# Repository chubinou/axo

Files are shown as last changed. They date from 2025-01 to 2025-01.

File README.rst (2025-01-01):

AXO
###

A simple eurorack logic module

* `axo` full schematics
* `axo_back` main board
* `axo_middle` connector board
* `axo_front` face plate

LICENSE
#######

This work by Pierre Lamot is licensed under CC BY-NC 4.0. To view a copy of this license, visit https://creativecommons.org/licenses/by-nc/4.0/

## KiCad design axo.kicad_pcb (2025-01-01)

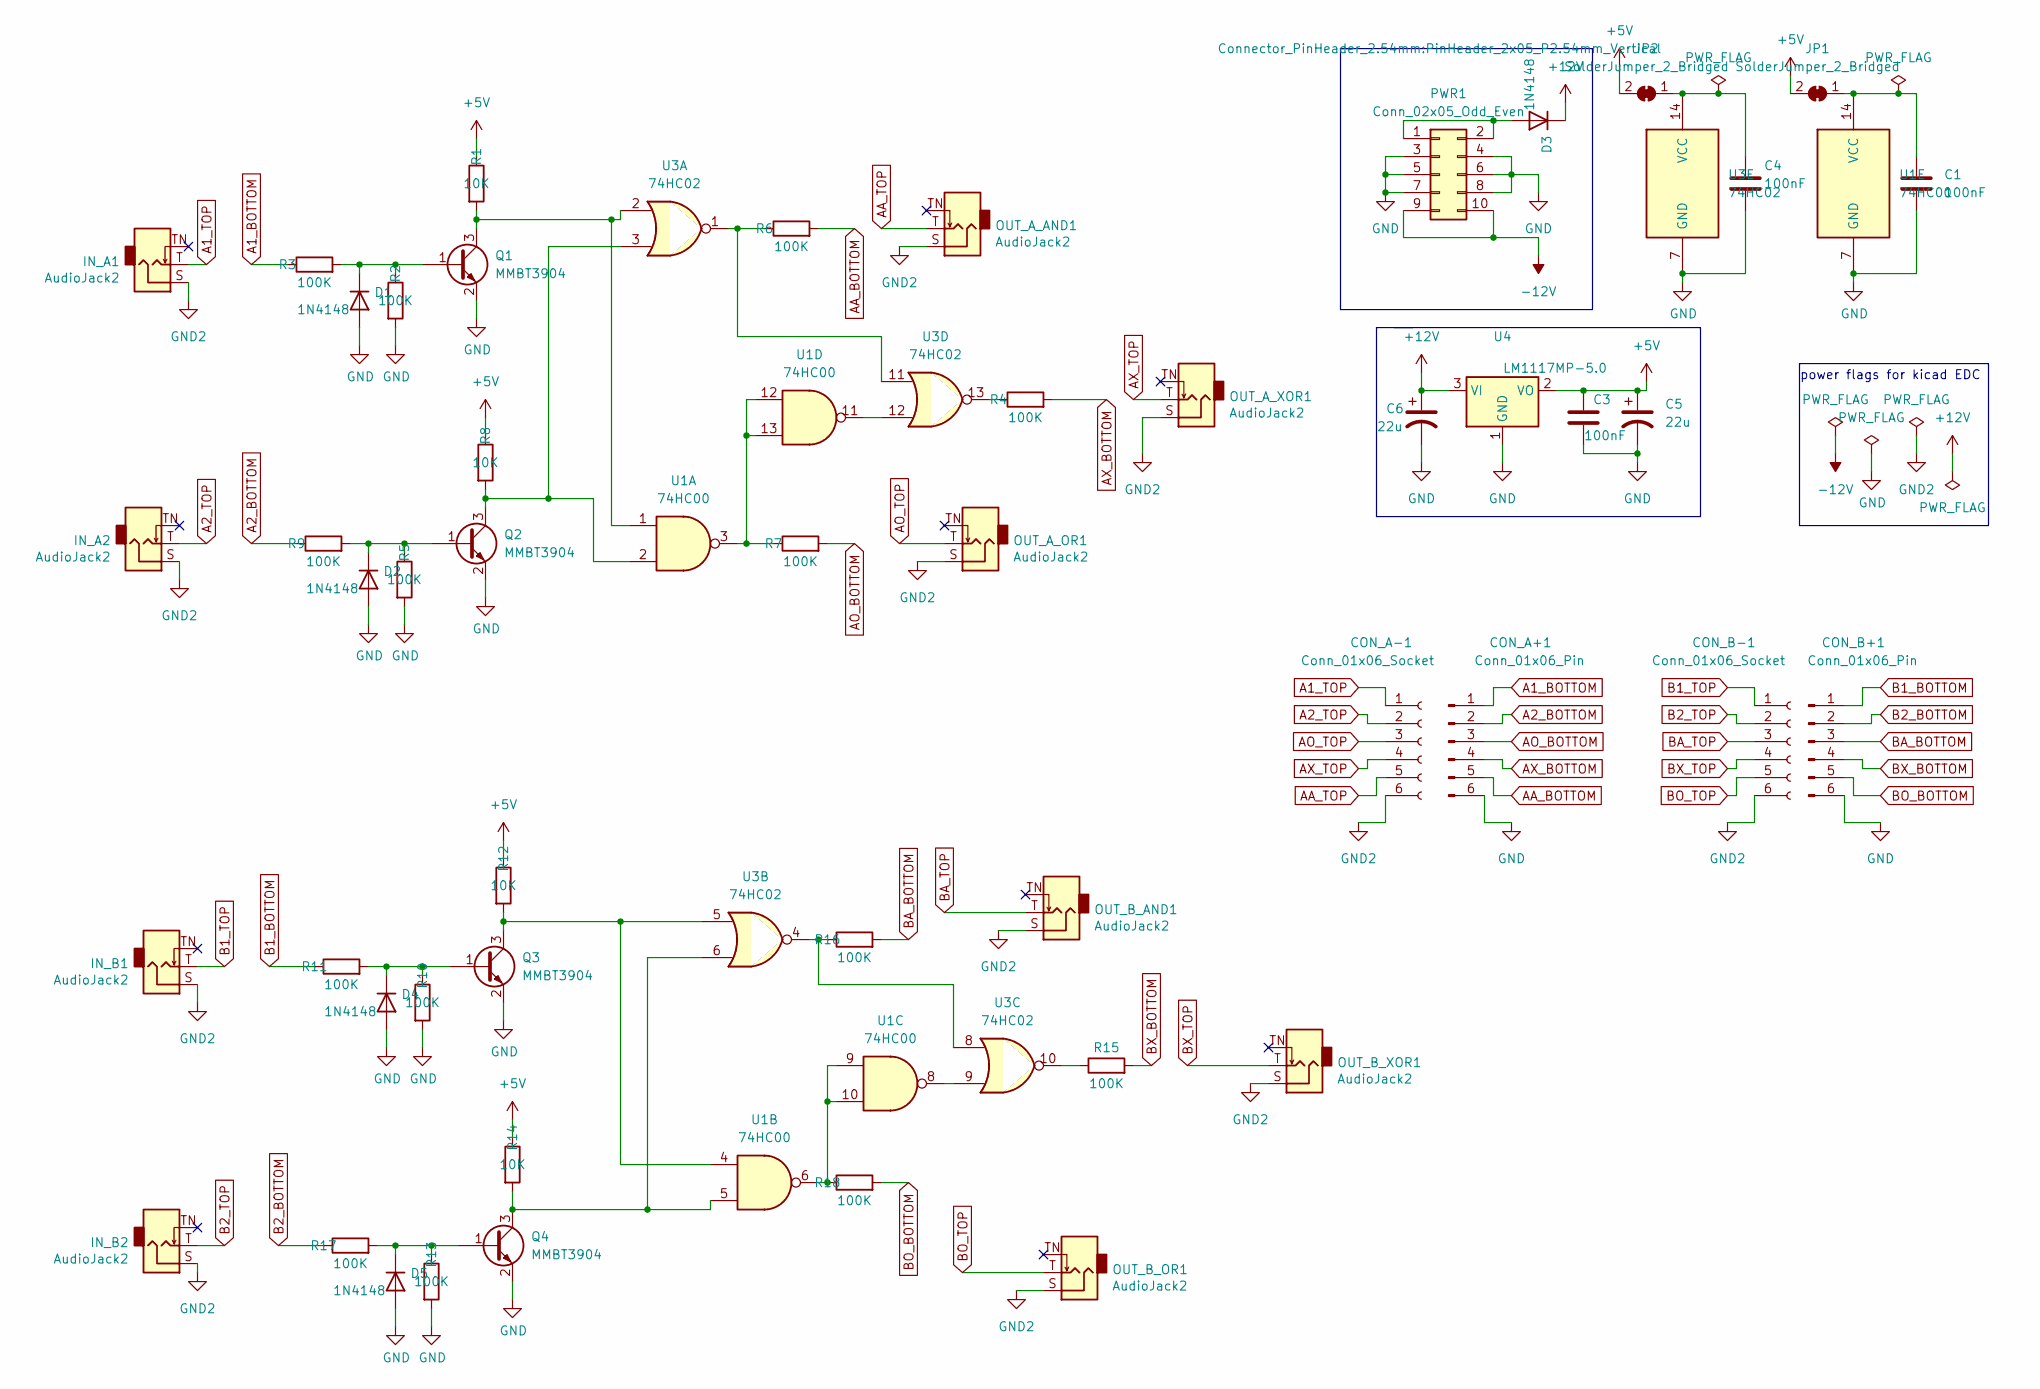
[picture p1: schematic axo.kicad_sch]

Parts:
C1, C3, C4: 100nF; C_0805_2012Metric; LCSC C49678
C5, C6: 22u; CP_Elec_6.3x5.4; LCSC C3001215
CON_A+1: Conn_01x06_Pin; PinHeader_1x06_P2.54mm_Vertical
CON_A-1: Conn_01x06_Socket; PinSocket_1x06_P2.54mm_Vertical
CON_B+1: Conn_01x06_Pin; PinHeader_1x06_P2.54mm_Vertical
CON_B-1: Conn_01x06_Socket; PinSocket_1x06_P2.54mm_Vertical
D1, D2, D3, D4, D5: 1N4148; D_SOD-323; LCSC C2128
IN_A1, IN_A2: AudioJack2; Jack_3.5mm_QingPu_WQP-PJ398SM_Vertical
IN_B1, IN_B2: AudioJack2; Jack_3.5mm_QingPu_WQP-PJ398SM_Vertical
JP1, JP2: SolderJumper_2_Bridged; SolderJumper-2_P1.3mm_Bridged_Pad1.0x1.5mm
OUT_A_AND1: AudioJack2; Jack_3.5mm_QingPu_WQP-PJ398SM_Vertical
OUT_A_OR1: AudioJack2; Jack_3.5mm_QingPu_WQP-PJ398SM_Vertical
OUT_A_XOR1: AudioJack2; Jack_3.5mm_QingPu_WQP-PJ398SM_Vertical
OUT_B_AND1: AudioJack2; Jack_3.5mm_QingPu_WQP-PJ398SM_Vertical
OUT_B_OR1: AudioJack2; Jack_3.5mm_QingPu_WQP-PJ398SM_Vertical
OUT_B_XOR1: AudioJack2; Jack_3.5mm_QingPu_WQP-PJ398SM_Vertical
PWR1: Conn_02x05_Odd_Even; PinHeader_2x05_P2.54mm_Vertical
Q1, Q2, Q3, Q4: MMBT3904; SOT-23; LCSC C20526
R1, R8, R12, R14: 10K; R_0603_1608Metric; LCSC C25804
R2, R3, R4, R5, R6, R7, R9, R10, R11, R13, R15, R16, R17, R18: 100K; R_0603_1608Metric; LCSC C25803
U1: 74HC00; SOIC-14_3.9x8.7mm_P1.27mm; LCSC C155451
U3: 74HC02; SOIC-14_3.9x8.7mm_P1.27mm; LCSC C5588
U4: LM1117MP-5.0; SOT-223; LCSC C6187

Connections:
+5V: C3.1, C5.1, JP1.2 (B), JP2.2 (B), R1.1, R8.1, R12.1, R14.1, U4.2 (VO)
+12V: C6.1, D3.1 (K), U4.3 (VI)
-12V: PWR1.9, PWR1.10
A1_BOTTOM: CON_A+1.1, R3.1
A1_TOP: CON_A-1.1, IN_A1.T
A2_BOTTOM: CON_A+1.2, R9.1
A2_TOP: CON_A-1.2, IN_A2.T
AA_BOTTOM: CON_A+1.5, R6.2
AA_TOP: CON_A-1.5, OUT_A_AND1.T
AO_BOTTOM: CON_A+1.3, R7.2
AO_TOP: CON_A-1.3, OUT_A_OR1.T
AX_BOTTOM: CON_A+1.4, R4.2
AX_TOP: CON_A-1.4, OUT_A_XOR1.T
B1_BOTTOM: CON_B+1.1, R11.1
B1_TOP: CON_B-1.1, IN_B1.T
B2_BOTTOM: CON_B+1.2, R17.1
B2_TOP: CON_B-1.2, IN_B2.T
BA_BOTTOM: CON_B+1.3, R16.2
BA_TOP: CON_B-1.3, OUT_B_AND1.T
BO_BOTTOM: CON_B+1.5, R18.2
BO_TOP: CON_B-1.5, OUT_B_OR1.T
BX_BOTTOM: CON_B+1.4, R15.2
BX_TOP: CON_B-1.4, OUT_B_XOR1.T
GND: C1.2, C3.2, C4.2, C5.2, C6.2, CON_A+1.6, CON_B+1.6, D1.2 (A), D2.2 (A), D4.2 (A), D5.2 (A), PWR1.3, PWR1.4, PWR1.5, PWR1.6, PWR1.7, PWR1.8, Q1.2 (E), Q2.2 (E), Q3.2 (E), Q4.2 (E), R2.2, R5.2, R10.2, R13.2, U1.7 (GND), U3.7 (GND), U4.1 (GND)
GND2: CON_A-1.6, CON_B-1.6, IN_A1.S, IN_A2.S, IN_B1.S, IN_B2.S, OUT_A_AND1.S, OUT_A_OR1.S, OUT_A_XOR1.S, OUT_B_AND1.S, OUT_B_OR1.S, OUT_B_XOR1.S
unnamed: D1.1 (K), Q1.1 (B), R2.1, R3.2
unnamed: D2.1 (K), Q2.1 (B), R5.1, R9.2
unnamed: D3.2 (A), PWR1.1, PWR1.2
unnamed: D4.1 (K), Q3.1 (B), R10.1, R11.2
unnamed: D5.1 (K), Q4.1 (B), R13.1, R17.2
unnamed: C1.1, JP1.1 (A), U1.14 (VCC)
unnamed: C4.1, JP2.1 (A), U3.14 (VCC)
unnamed: Q1.3 (C), R1.2, U1.1, U3.2
unnamed: Q2.3 (C), R8.2, U1.2, U3.3
unnamed: Q3.3 (C), R12.2, U1.4, U3.5
unnamed: Q4.3 (C), R14.2, U1.5, U3.6
unnamed: R4.1, U3.13
unnamed: R6.1, U3.1, U3.11
unnamed: R7.1, U1.3, U1.12, U1.13
unnamed: R15.1, U3.10
unnamed: R16.1, U3.4, U3.8
unnamed: R18.1, U1.6, U1.9, U1.10
unnamed: U1.8, U3.9
unnamed: U1.11, U3.12

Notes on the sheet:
power flags for kicad EDC

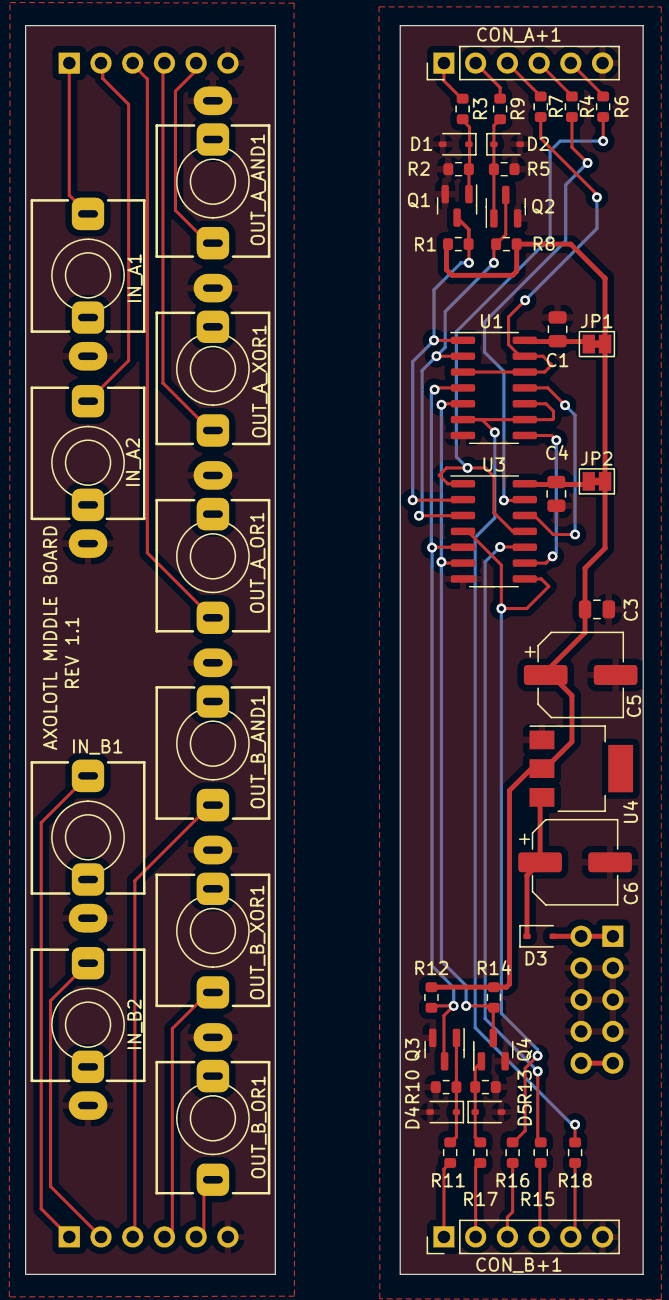
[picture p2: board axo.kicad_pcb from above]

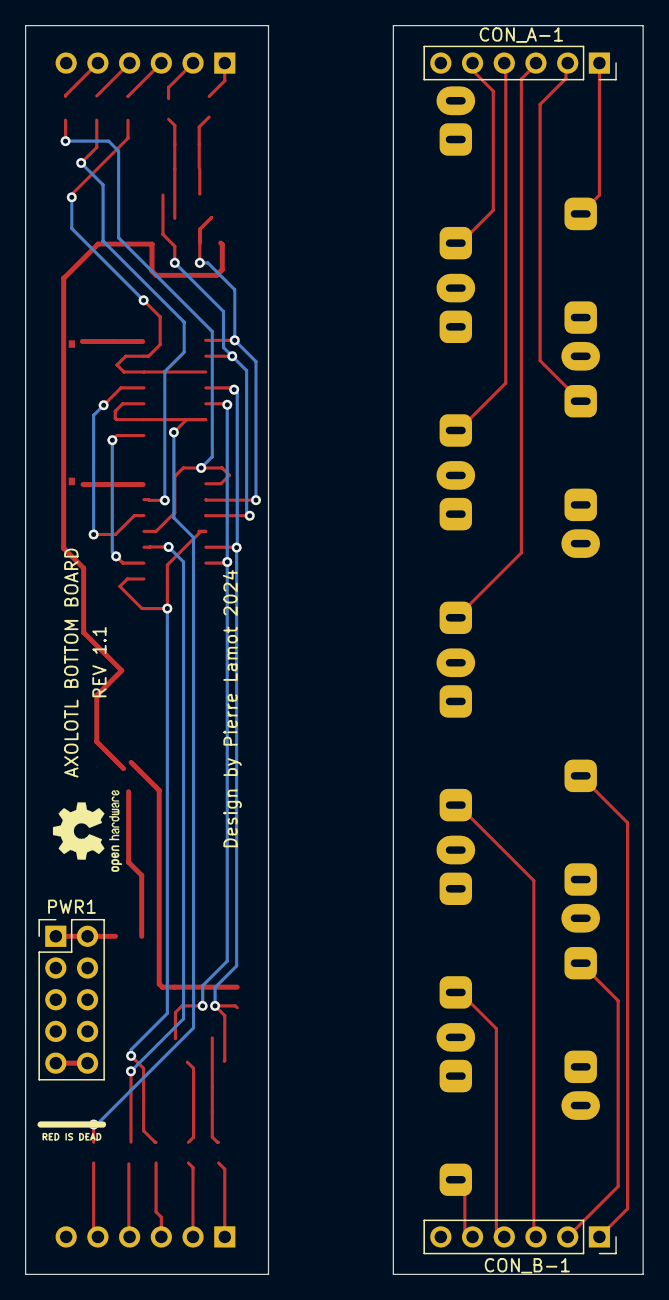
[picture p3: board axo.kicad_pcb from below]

Board: 2 copper layers, 49.4 x 100.0 mm, 52 parts (3 on the bottom side), 44 nets.

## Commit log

2024-01-28 axo: init
    [axo.kicad_pcb, axo.kicad_sch, axo_front.kicad_pcb]
2024-02-01 replace xor by nand/nor logic
    [axo.kicad_pcb, axo.kicad_sch]
2024-02-10 update pcb
    [axo_back.kicad_pcb, axo_front.kicad_pcb, axo_middle.kicad_pcb]
2025-01-01 add readme
    [axo.kicad_pcb, axo.kicad_sch, axo_back.kicad_pcb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]
